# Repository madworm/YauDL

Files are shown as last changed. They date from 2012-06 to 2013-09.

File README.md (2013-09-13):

YauDL
=====

LAYOUT FILES: (Y)et (a)nother (u)seless (D)ummy (L)oad

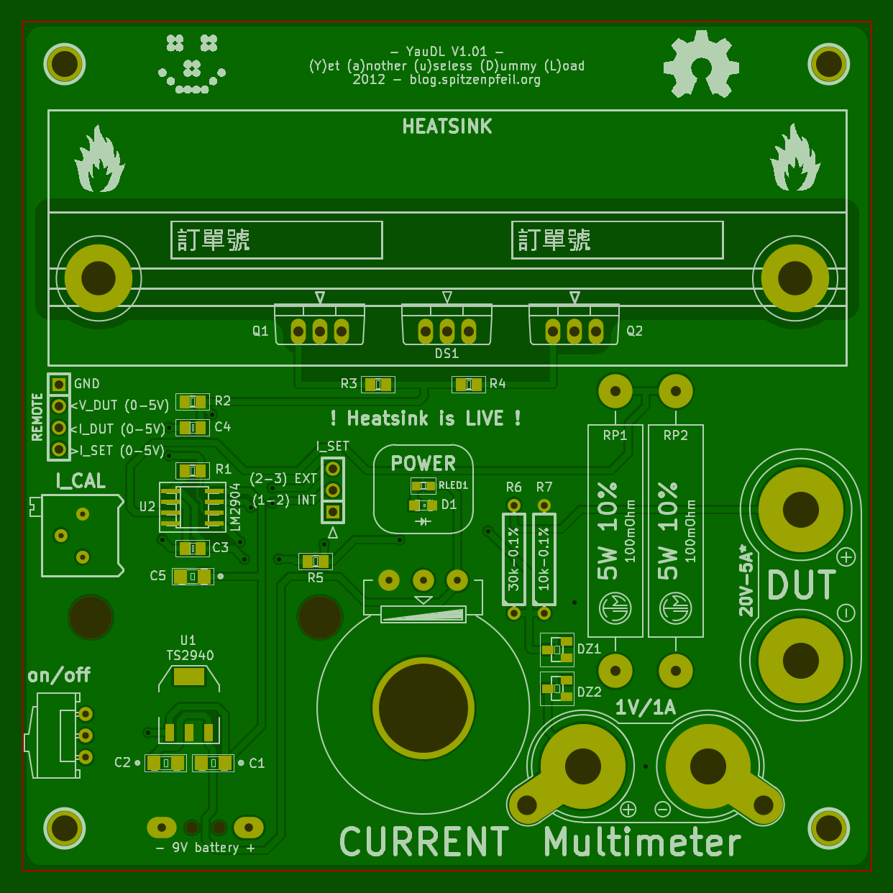
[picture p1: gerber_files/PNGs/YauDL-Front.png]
YauDL-Front


For testing various projects I desire an adjustable constant current sink.
Nothing fancy, not microcontroller controlled, not 'constant power', maybe
with a display, maybe just use a DMM for that. BUT I need AMPS!
I'm shooting for a device that is capable to sink 5A. At least for a limited
amount of time, a couple of minutes should be enough to see if the DUT
overheats and/or craps out.

It will be as simple as can be: MOSFET(s), heatsink, sense resistor(s),
opamp(s), gain control, reference voltage, multi-turn pot to set the
reference current. It may or may not come with binding posts.

The first opamp will amplify the voltage drop on the mOhm range sense resistor
to a useful value (1V --> 1A), the second opamp will be wired in the usual
follower setup driving the MOSFET(s). I don't want to use a 1R sense resistor,
as this causes the device to need at least 5V for 5A. I'm aiming at something
lower.

BTW. It is strictly for DC input voltages.

---

Before having PC-boards made, please make sure you know about your manufacturer's peculiarities!
Especially drill-sizes and their tolerances may vary too much and give you trouble.

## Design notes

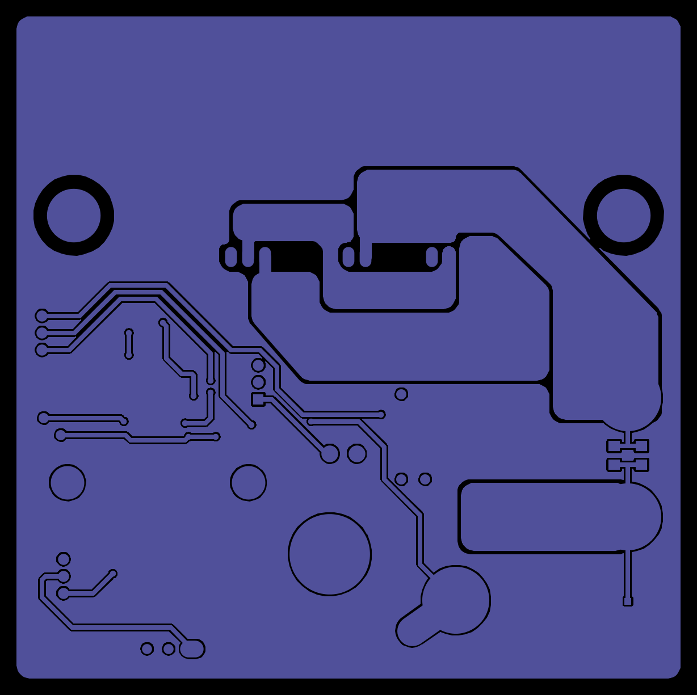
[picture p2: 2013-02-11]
gerber_files/PNGs/YauDL-Back.gbl.png

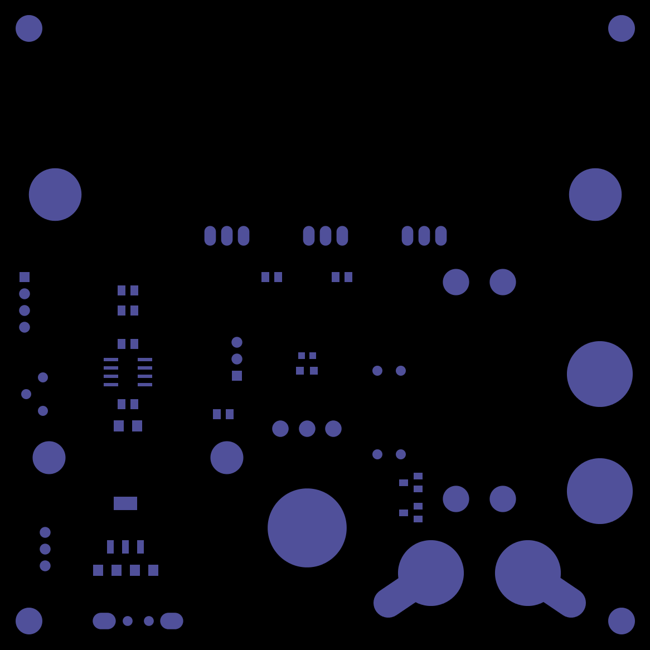
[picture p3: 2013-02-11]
gerber_files/PNGs/YauDL-F_Mask.gts.png

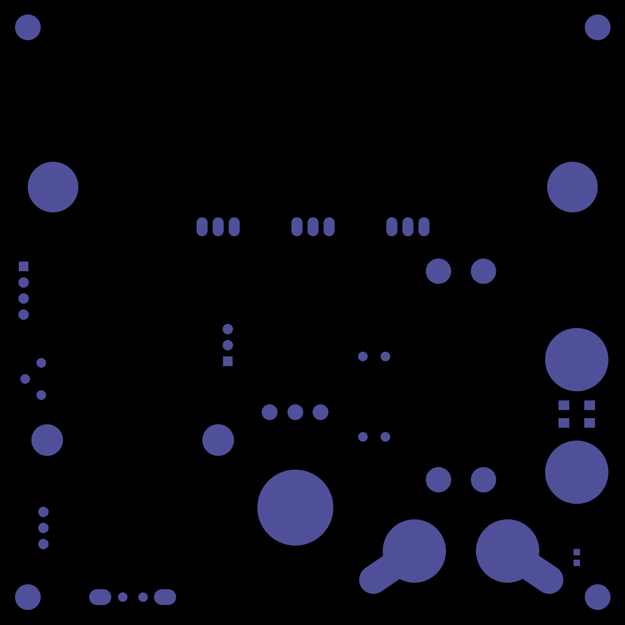
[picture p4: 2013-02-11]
gerber_files/PNGs/YauDL-B_Mask.gbs.png

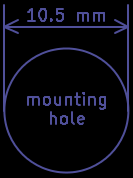
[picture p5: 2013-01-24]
gerber_files/PNGs/YauDL-Eco1_User.gbr.png

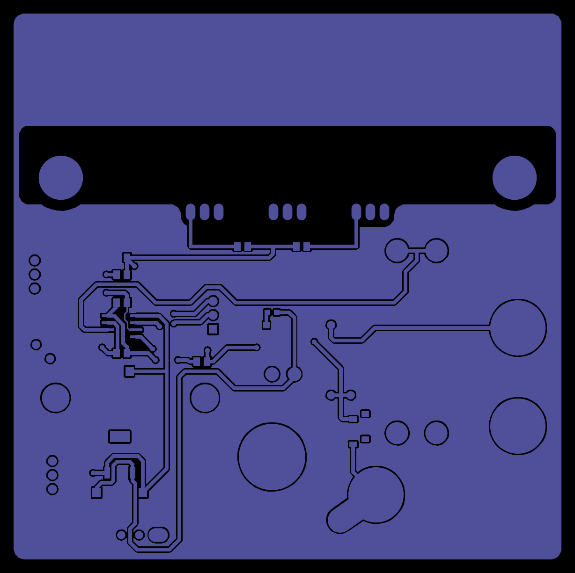
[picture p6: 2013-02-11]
gerber_files/PNGs/YauDL-Front.gtl.png

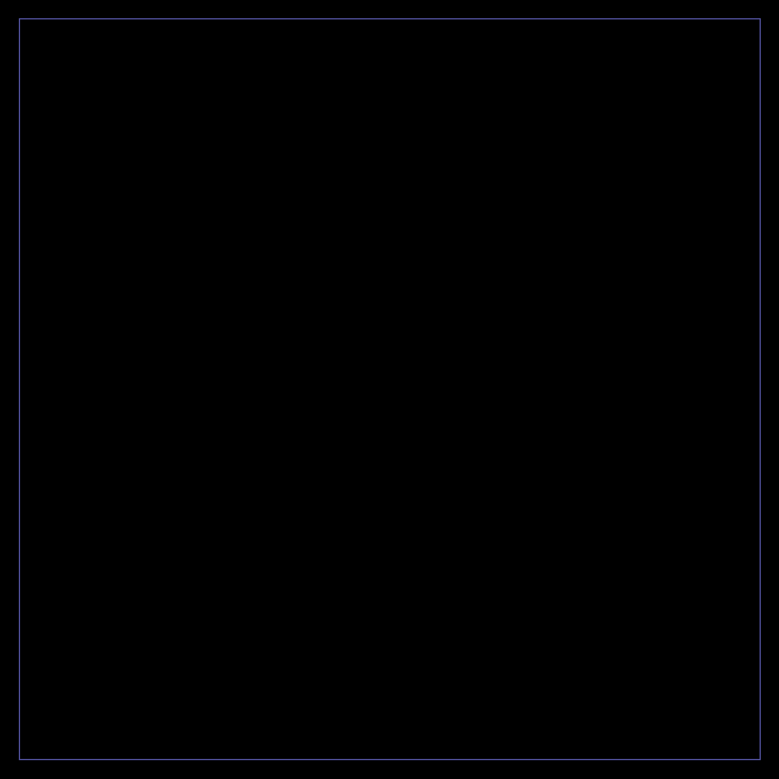
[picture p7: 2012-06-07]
gerber_files/PNGs/YauDL-Edge_Cuts.gbr.png

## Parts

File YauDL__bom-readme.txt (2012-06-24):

The "bom" pdf file is a "hybrid". If you open it with LibreOffice,
you can edit the original file.

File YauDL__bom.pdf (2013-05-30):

## YauDL 1.00 – part list

Part | Identifier
BZX84C-5V6, Zener diode, SOT23 | DZ1, DZ2
LM2904 dual opamp, SO-8 | U2
TS2940, 5V low drop regulator, SOT223 | U1
LED, 0805 | D1
0R resistor, 0603 | RGND1
100R resistor, 0805 | R3, R4
470R resistor, 0603 | RLED1
10k resistor, 0805 | R1, R5
100k resistor, 0805 | R2
100nF ceramic capacitor, 0805 | C3, C4
10µF TANTALUM capacitor, 1206 | C1, C2
10µF ceramic capacitor, 1206 | C5, C6, C7 | Do not populate C5
1k resistor, 0603 | | For stable operation of U1
Part | Identifier
IRL3803, N-CH MOSFET, TO-220 | Q1, Q2 | In the bag(s)
MBR1045, Schottky diode, 45V, 10A, TO-220 | DS1 | ''
Vishay 534 20k 10-turn potentiometer | RV2 | ''
Vishay Spectrol 64P-104, 100k 25-turn trimmer | RV1 | ''
100mOhm power resistor, 5W, Vitrohm KH208-8 | PR1, PR2 | ''
10k resistor, through-hole, 0.1% | R7 | ''
30k resistor, through-hole, 0.1% | R6 | ''
metal hex stand-off, 25mm, M3 mounting hole | MH1, MH2, MH3, MH4 | ''
9V battery clip with leads | BT1 | ''
binding post, 4mm banana, M4 mounting hole | T1, T2, T3, T4 | ''
heatsink + TO-220 clips, Alutronic PR127/94/M3 | HS1 | ''
board-edge on/off switch, SPDT, ECE ESP2010 | SW1 | ''
header 4pin | P1 | ''
header, male 3pin | JP1 | ''
jumper | JP1 | ''

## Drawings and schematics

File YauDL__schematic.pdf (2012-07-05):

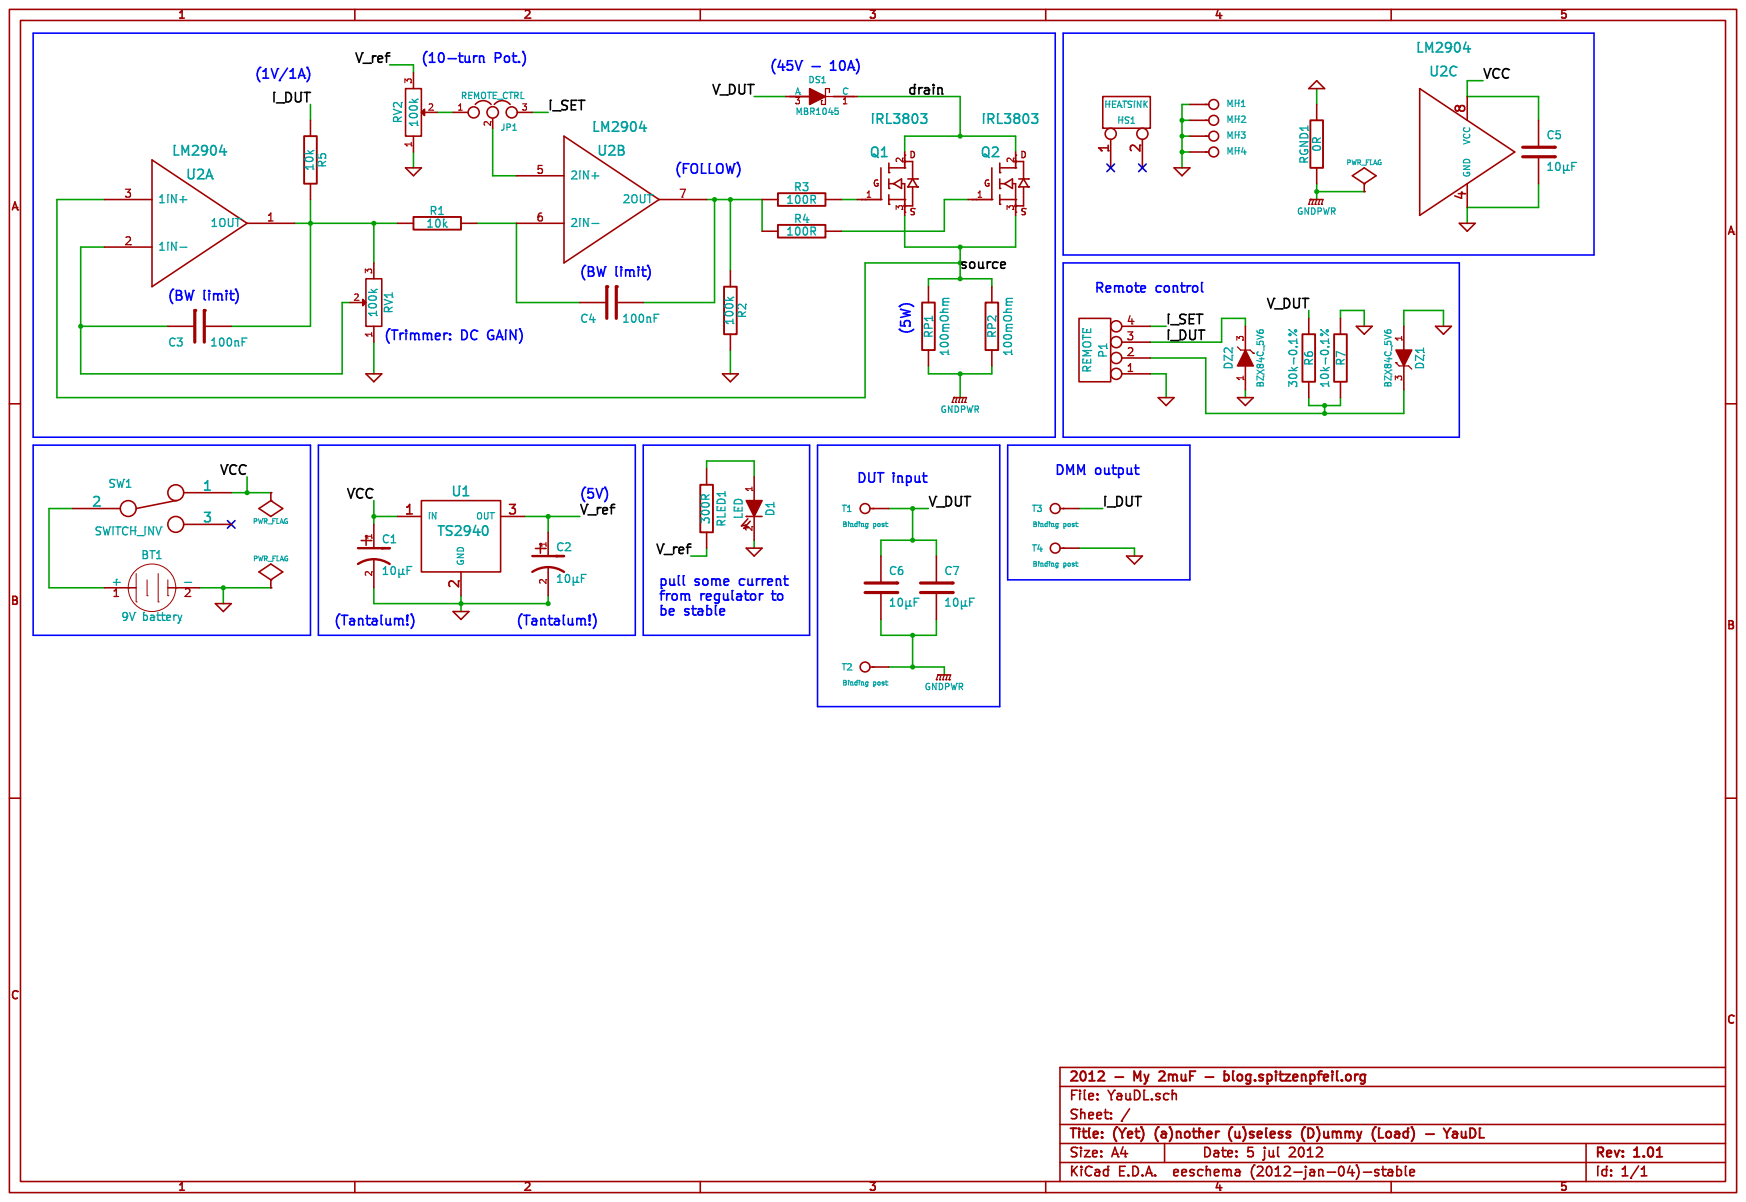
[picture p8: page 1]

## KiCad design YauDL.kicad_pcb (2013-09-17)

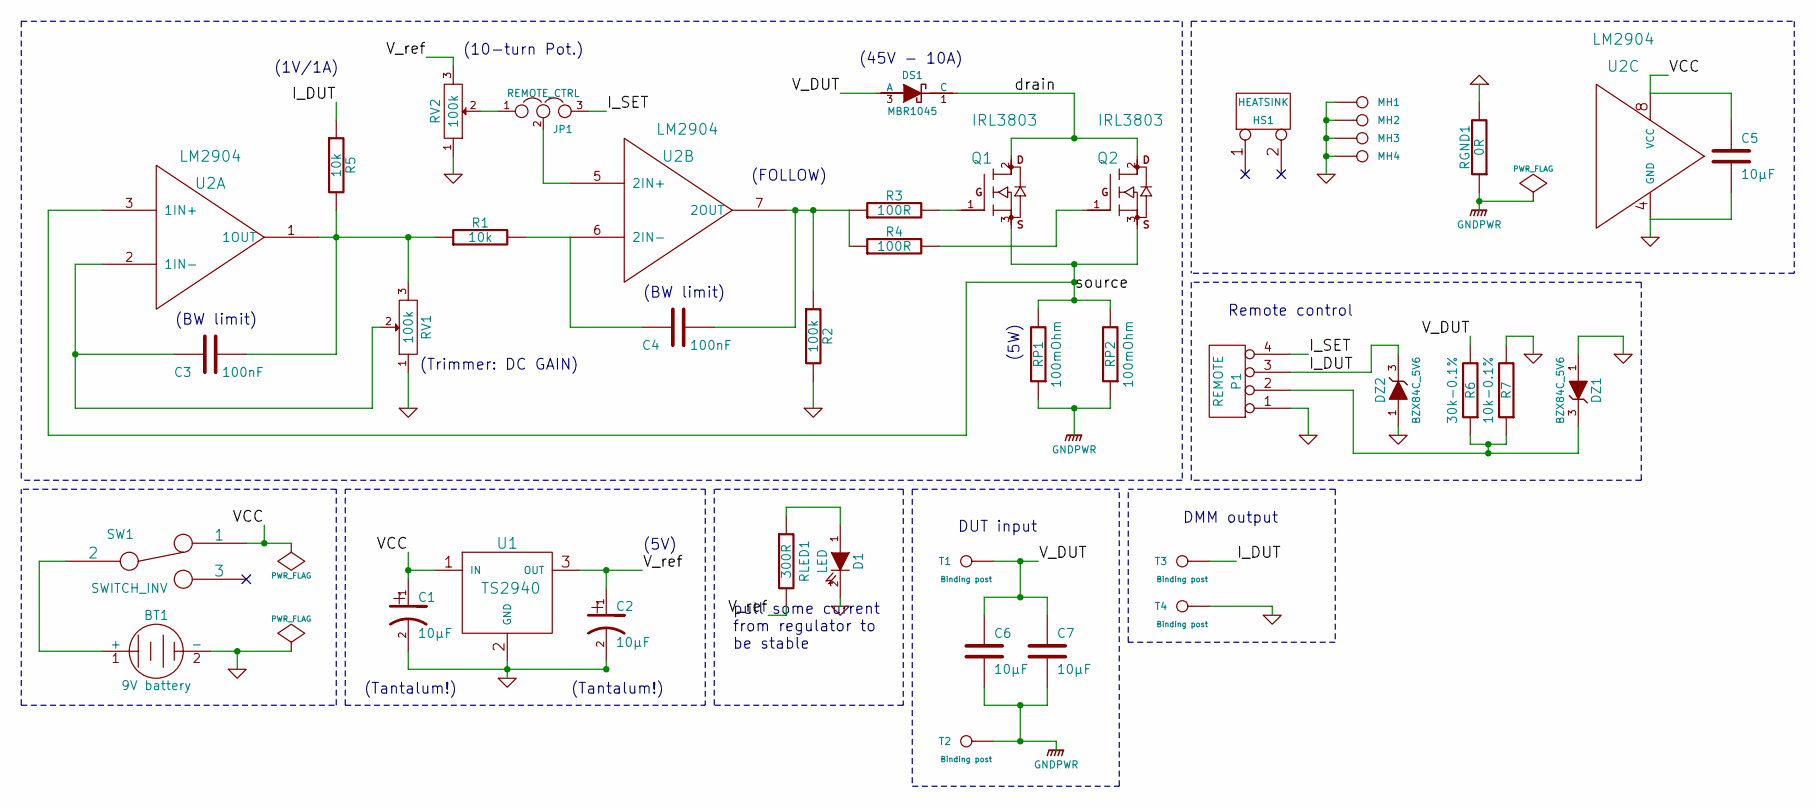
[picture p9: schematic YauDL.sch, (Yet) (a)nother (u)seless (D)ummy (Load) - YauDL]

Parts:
BT1: 9V battery
C1, C2, C5, C6, C7: 10µF
C3, C4: 100nF
D1: LED
DS1: MBR1045
DZ1, DZ2: BZX84C_5V6
HS1: HEATSINK
JP1: REMOTE_CTRL
MH1, MH2, MH3, MH4: CONN_1
P1: REMOTE
Q1, Q2: IRL3803
R1, R5: 10k
R2: 100k
R3, R4: 100R
R6: 30k-0.1%
R7: 10k-0.1%
RGND1: 0R
RLED1: 300R
RP1, RP2: 100mOhm
RV1, RV2: 100k
SW1: SWITCH_INV
T1, T2, T3, T4: Binding post
U1: TS2940
U2: LM2904

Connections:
/I_DUT: DZ2.3, P1.3, R5.1, T3.1
/I_SET: JP1.3, P1.4
/VCC: C1.1, C5.1, SW1.1, U1.1 (IN), U2.8 (VCC)
/V_DUT: C6.1, C7.1, DS1.3 (A), R6.2, T1.1
/V_ref: C2.1, RLED1.2, RV2.3, U1.3 (OUT)
/drain: DS1.1 (C), Q1.2 (D), Q2.2 (D)
/source: Q1.3 (S), Q2.3 (S), RP1.2, RP2.2, U2.3 (1IN+)
GND: BT1.2 (-), C1.2, C2.2, C5.2, D1.2 (K), DZ1.1, DZ2.1, MH1.1, MH2.1, MH3.1, MH4.1, P1.1, R2.2, R7.2, RGND1.2, RV1.1, RV2.1, T4.1, U1.2 (GND), U2.4 (GND)
GNDPWR: C6.2, C7.2, RGND1.1, RP1.1, RP2.1, T2.1
unnamed: D1.1 (A), RLED1.1
unnamed: C4.2, R2.1, R3.1, R4.1, U2.7 (2OUT)
unnamed: Q1.1 (G), R3.2
unnamed: C3.2, R1.1, R5.2, RV1.3, U2.1 (1OUT)
unnamed: C4.1, R1.2, U2.6 (2IN-)
unnamed: JP1.2, U2.5 (2IN+)
unnamed: BT1.1 (+), SW1.2
unnamed: JP1.1, RV2.2
unnamed: Q2.1 (G), R4.2
unnamed: DZ1.3, P1.2, R6.1, R7.1
unnamed: C3.1, RV1.2, U2.2 (1IN-)

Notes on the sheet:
Remote control
(45V - 10A)
pull some current from regulator to be stable
(Tantalum!)
(BW limit)
(5W)
DMM output
(10-turn Pot.)
(5V)
(FOLLOW)
(Trimmer: DC GAIN)
(1V/1A)
DUT input

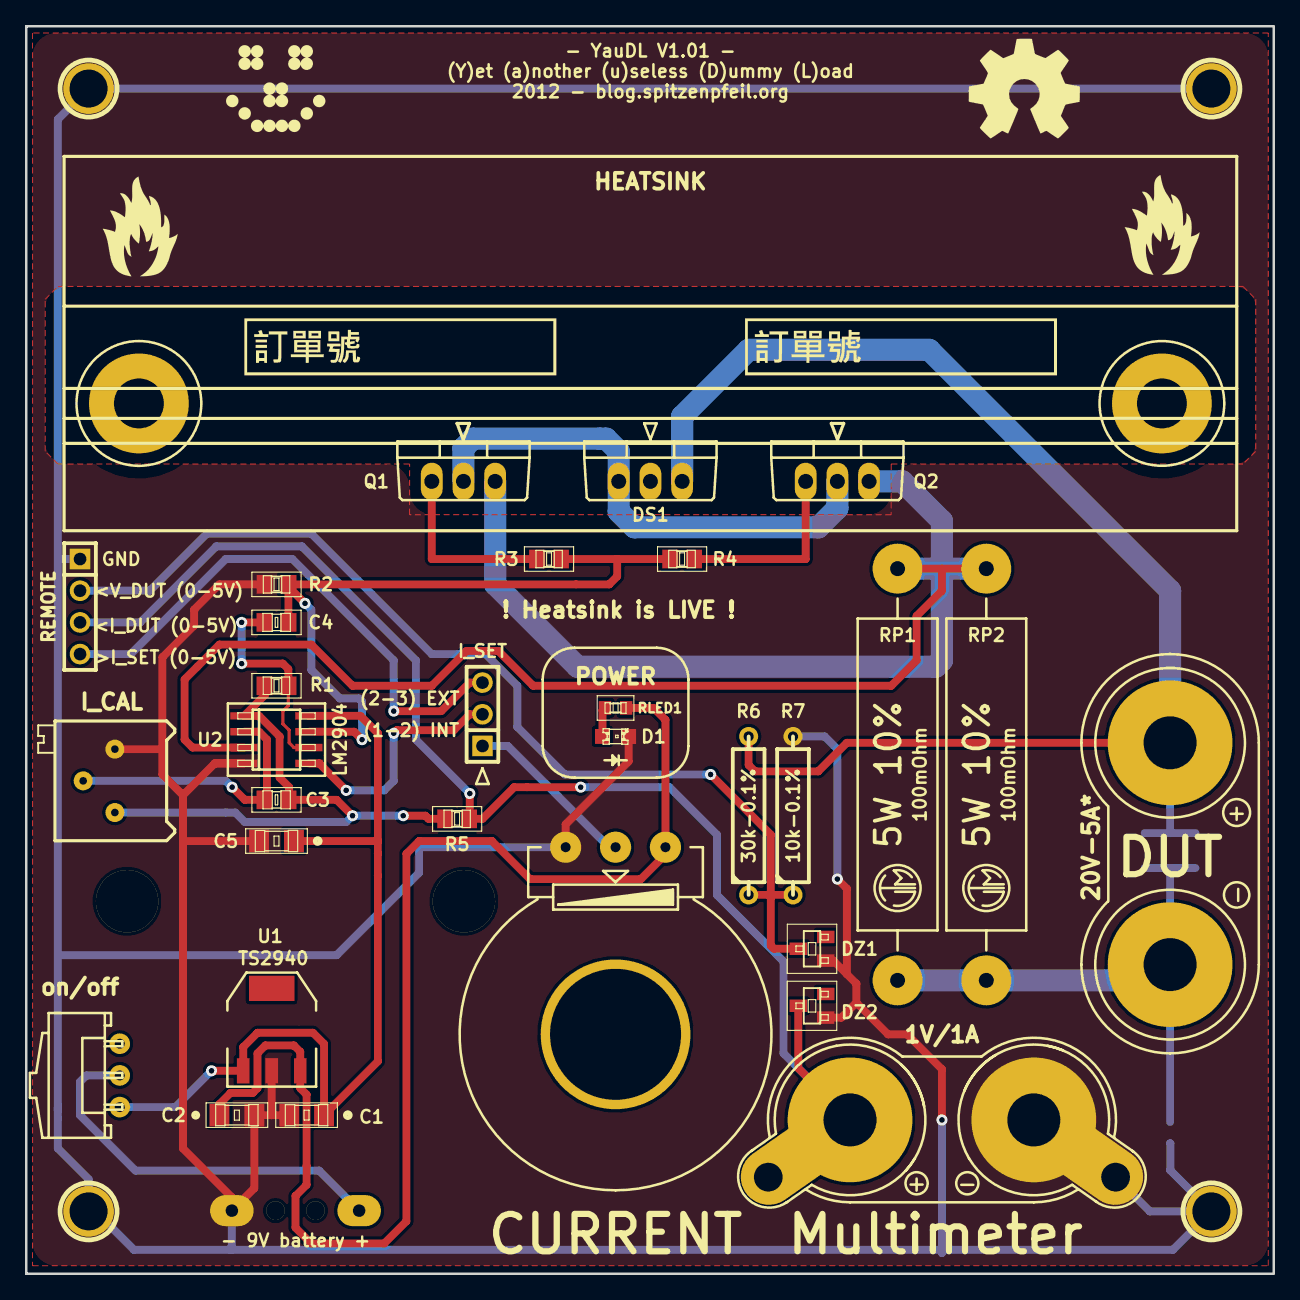
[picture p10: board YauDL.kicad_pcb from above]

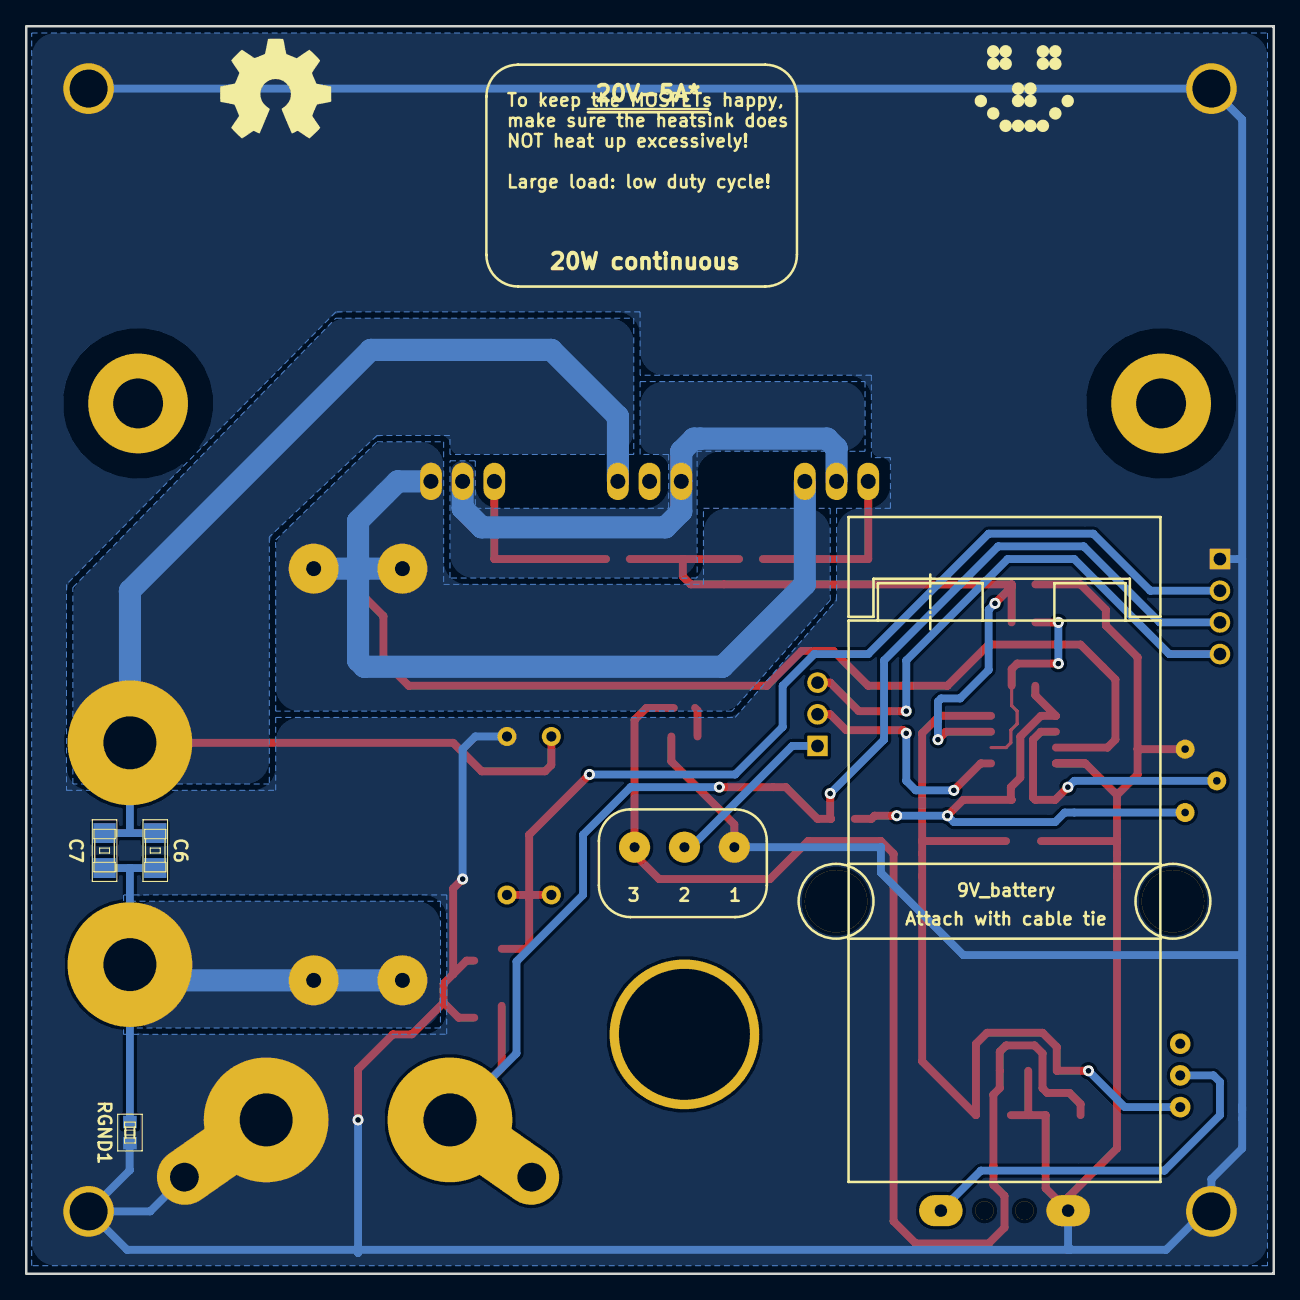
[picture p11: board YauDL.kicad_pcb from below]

Board: 2 copper layers, 100.0 x 100.0 mm, 49 parts (6 on the bottom side), 20 nets.

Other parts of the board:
G1, G2: LED_SMILE
G3, G4: OSHW_LOGO
G5, G6: FIRE
G7, G8: CHINESE_ORDER_NUMBER

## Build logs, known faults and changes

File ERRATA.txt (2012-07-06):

V1.00:
------

(1)	Don't populate C5. It interferes with the cable tie.

(2)	Make sure the 'I_SET' jumper is 100% FLUSH on the bottom
	of the circuit board, so it doesn't interfere with the
	battery. Add 1 layer of tesa-strip around the battery for
	additional insulation in that area.

(3)	TS2940CW50 - voltage regulator unstable _again_
	
	Change LED resistor (RLED1) to allow for 10mA of current.

(4)	The BZX84C-5V1 Zener diodes open too early and clip at
	about 4.50V instead of slightly above 5V. This limits the
	usable input voltage range to about 0-18V-ish. They should
	be replaced with 5V6 ones. The input-protection diodes of
	a 5V tolerant microcontroller should do the rest.

	The 5V6 diodes clamp at about 5.6V to 5.7V. The output
	resistance on the V_DUT pin is 30k. Assuming an overvoltage
	condition with 25V on the DUT input, the protection diodes
	of an attached 5V micro-controller should be able to cope with
	5.7V and a maximum current of about 0.8mA.

V0.1:
-----

(6)	Replace the MOSFET based RPP with a single Schottky Diode:
	MBR1045 - TO-220 package. 45V, 10A. Forward voltage of 
	0.5V at 5A --> 2.5W. Should survive without a large HS.

(5)	If you require high current with input voltages below 5V,
	the reverse polarity protection tends to heat up a lot.

	DON'T populate: Q3, Q4, R7, DZ1

	Place a 2mm jumper wire between JP1 and JP2 to override.
	This will avoid the magic blue smoke.

(4)	Added 2x 47µF electrolytic capacitors across the DUT
	terminals (back to back --> non polarized).

(3)	TS2940CW50 - Voltage regulator unstable.

	Change LED resistor to 470Ohm to draw more current.
	This removes all output voltage oscillations.	

(2)	TS2940CW50 - Voltage regulator unstable.

	C1 and C2 MUST be tantalum capacitors!	

(1)	TS2940CW50 - Voltage regulator unstable.

	Don't populate C2 (output capacitor).
	
	The datasheet mentions a minimum load of 10mA for the thing
	to be stable. I couldn't get rid of massive output voltage oscillations
	as long as C2 was populated, although I added a 100Ohm resistor to
	draw about 50mA. Tried a different regulator, different cap as well.
	I've never experienced such misbehaviour before. It worked just fine
	in previous projects...

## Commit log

2012-06-02 Fixed a typo.
    [YauDL.brd, YauDL.sch]
2012-06-02 Added a preliminary BOM.
2012-06-02 First doodles.
    [YauDL.brd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]
2012-06-03 Schematic work.
    [YauDL.brd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]
2012-06-05 Doodle of doodles.
    [YauDL.brd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]
2012-06-05 Added a proper switch + footprint + calibration pot now flat on pcb.
    [YauDL.brd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]
2012-06-06 Sending this one out for review I guess.
    [YauDL-Back.gbl, YauDL-Eco1.gbr, YauDL-Front.gtl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]
2012-06-06 It is a 10.5mm mounting hole - not 10.6mm
    [YauDL-Back.gbl, YauDL-Eco1.gbr, YauDL-Front.gtl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]
2012-06-06 Switched to high-power resistors + added a RPP override shunt.
    [YauDL-Back.gbl, YauDL-Eco1.gbr, YauDL-Front.gtl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]
2012-06-07 Gate/source pins of the IRLZ34N were swapped ;-(
    Both the library and the footprint were wrong. Now I made my own.
    The IRLZ34N TO-220 (fullpack) has this pinout (front view, pins down):
    1 gate
    2 drain
    3 source
    The AO3401 P-MOSFET (SOT23) on the other hand has:
    1 gate
    2 source
    3 drain
    [YauDL-Back.gbl, YauDL-Eco1.gbr, YauDL-Front.gtl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]
2012-06-07 Updated the BOM.
2012-06-09 Added a low-pass filter (RC=100ms) to the output opamp.
    LTSpice simulations indicated oscillation at higher currents.
    Hopefully the real thing doesn't require it, but I can bodge it.
    [YauDL-Back.gbl, YauDL-Eco1.gbr, YauDL-Front.gtl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]
2012-06-09 BOM updated. Now we're at V0.2 for both the schematic and the layout.
2012-06-09 Had to add some more caps and stuff. The PCB order will go into the trash.
    [YauDL-Back.gbl, YauDL-Eco1.gbr, YauDL-Front.gtl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]
2012-06-11 New FET: IRL3803 TO-220 (150W dissip.) + some silkscreen tweaks.
    [YauDL-Back.gbl, YauDL-Eco1.gbr, YauDL-Front.gtl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]
2012-06-11 Silkscreen tweaks regarding power input and duty cycle.
    [YauDL.brd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]
2012-06-13 Added 2x 10µF ceramic caps across the DUT input.
    [YauDL-Back.gbl, YauDL-Eco1.gbr, YauDL-Front.gtl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]
2012-06-14 Added another BOM. The information in there shall be hidden forever ;-)
2012-06-15 Silkscreen update.
    [YauDL.brd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]
2012-06-15 Some fixes:
    * The TS2940CW50 voltage regulatr NEEDS tantalum capacitors!
    * Changed the LED resistor to 470R to pull minimum current from
    regulator to make it stable. Otherwise it oscillates badly.
    [YauDL.brd, YauDL.sch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]
2012-06-15 V0.1 errata: back-to-back capacitors across DUT terminals.
2012-06-16 Addendum to the BOM.
2012-06-16 The MOSFETs need good cooling. The following is done to achieve it:
    * NO insulation of the TO-220 tabs that would impede heat transfer
    * Use thermal goop to improve things even more
    As the heatsink is now LIVE (up to 20V) and we don't want shorts
    * GND pour removed from underneath the heatsink's base + keepout
    * Added a warning to the top layer silkscreen
    [YauDL.brd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]
2012-06-16 Moved the MOSFETs closer together. Temperature should be equal.
    [YauDL.brd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]
2012-06-16 BOM fixed.
2012-06-17 RPP heats up when input voltage < 5V at high current. Fix needed.
2012-06-17 Added an inverting charge pump (TCM829).
    The reverse polarity protection using p-ch mosfets requires a
    minimum gate-source voltage for the fets to get a low enough
    R(ds)-on value. Otherwise they get HOT. By pulling the gate to
    -5V, V(gs) is sufficient even if the input voltage of the DUT
    is only a couple of volts (say 1-3V).
    [YauDL.brd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]
2012-06-17 Revert "Tweaks..."
    This reverts commit 0c1dc09ceebd5a01f0e86e24f0b4b3829b1a22fd.
    [YauDL.brd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]
2012-06-17 Revert "Added an inverting charge pump (TCM829)."
    This reverts commit de9563192d4ffa0c3c12e7bfe4f165a0f9cedcda.
    [YauDL.brd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]
2012-06-17 The on/off switch now switches VCC instead of GND. Silkscreen tweaks.
    [YauDL.brd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]
2012-06-17 Silkscreen tweaks.
    [YauDL.brd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]
2012-06-18 Added 2x 100R gate resistors for the power MOSFETs.
    [YauDL.brd, YauDL.sch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]
2012-06-18 Replaced the RPP with a beefy Schottky diode (MBR1045).
    [YauDL.brd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]
2012-06-18 Added the Schottky diode (MBR1045) to the V0.1 errata file.
2012-06-19 Updated the 'secret' BOM
2012-06-19 Moved binding posts a bit + added DMM probe holes.
    [YauDL.brd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]
2012-06-19 Dragon logo gone, OSHW logo instead.
    [YauDL.brd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]
2012-06-20 Added a dedicated area for 'factory text' on the PCB - in Chinese.
    [YauDL.brd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]
2012-06-20 Fixed the Chinese logo (crooked line).
    [YauDL.brd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]
2012-06-20 Updated the 'secret' BOM ;-)
2012-06-20 Increased the pad-size of the 25-turn trimmer a bit. It was too small.
    [YauDL.brd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]
2012-06-21 Added a remote-control option.
    * Header with: GND, I_DUT (0-5V out), V_DUT (0-5V out), I_SET (0-5V in)
    * Jumper to select between 'remote' and 'hand' operation
    * Voltage divider to scale 0-20 to 0-5V for V_DUT
    * 5.1V Zener diodes to limit output voltage of I_DUT and V_DUT
    [YauDL.brd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]
2012-06-21 Updated the BOM for V1.00
2012-06-21 Couldn't find any precision (0.1%) SMD resistors. Switched to DIP.
    [YauDL.brd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]
2012-06-21 Forgot to switch to through-hole for the 0.1% R in the BOM file.
2012-06-21 Forgot gerber update in '8fd0aff6de7db9c651f138ee2da098c7fb0b019b'.
    [YauDL-Back.gbl, YauDL-Front.gtl, YauDL-Mask_Back.gbs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]
2012-06-22 Moved C5 up a bit, so it doesn't get touched by the battery cable tie.
    [YauDL.brd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]
2012-06-24 Moved the BOM into a hybrid PDF file.
2012-07-02 Bugfixes for V1.00 --> V1.01
    * Moved the heatsink down about 0.5mm (20mil)
    * Moved the remote ctrl jumper, so it doesn't collide with the battery
    * Moved C5, so it doesn't interfere with the battery's cable tie
    [YauDL.brd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]
2012-07-02 Forgot to move the Chinese logos.
    [YauDL.brd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]
2012-07-05 Bugfixes to the schematic / BOM.
    * Changed RLED1 to 300R to pull more current. This should make the
    V-Reg. stable. Can't have 20mV oscillations on the output.
    * Changed the Zener diodes to 5V6 ones. With the sub 1mA current
    going through the precision voltage divider (R6/R7) these may
    finally clip at 5V - and not at 4.5V.
    [YauDL.brd, YauDL.sch]
2012-07-06 Updated the ERRATA file with information about the 5V6 Zener diodes.
2013-01-23 Increased drill size for pin-headers to 40mil.
    Did NOT recreate gerber files!
    [YauDL.brd]
2013-01-24 Recreated the gerber files (40mil drill size issue).
    [YauDL-B_Mask.gbs, YauDL-B_SilkS.gbo, YauDL-Back.gbl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]
2013-02-11 Increased annular ring for pin-headers.
    [YauDL-B_Mask.gbs, YauDL-B_SilkS.gbo, YauDL-Back.gbl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]
2013-05-30 Updated BOM pdf-file.
2013-06-27 Converted to new kicad board format.
    [YauDL.brd, YauDL.kicad_pcb]
2013-09-17 Fixed missing module definitions (pcbnew BZR 4319 was barfing).
    [YauDL.kicad_pcb]
2015-04-27 Fixed vertical offset of multi-line-text.
    Some time ago KiCad changed how it handles that.
    [YauDL.sch]
